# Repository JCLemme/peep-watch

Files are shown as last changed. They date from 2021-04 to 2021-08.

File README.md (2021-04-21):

# peep watch

I'm attempting to build some real nice rebbleos hardware. 

---

## the watches

Right now there's just the "big board" prototype. After that there'll be a smaller prototype that can actually be worn on the body and then, hopefully, an actually small watch. (assuming all the prototypes work as designed lol).

## contributing

Hit me up on the discord, documentation is still pretty light.

Datasheets go in ./common/datasheets, kicad libraries in ./common/kicad-libs. I've been using the nightly kicad 5.99 builds.

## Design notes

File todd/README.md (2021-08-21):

# "todd" prototype watch

Ok so this is the "big board" prototype. Everything broken out, huge pcb, erring on the side of excess, etc. Hopefully this design can just be taken and crammed onto a tiny lil board when we're ready to make some wearable prototypes.

[See the schematic here](./sch_export/todd_watch.pdf)

---

## theory of design

I'm trying to not stray too far from the designs of the original run of pebbles. I'm all in for messing with the "formula" in the future but right now we need more of the same, yeah? With that in mind the feature set hits the same notes:

* 32bit ARM cpu @ 128mhz with ~512k RAM
* 64mb flash storage
* JDI memory-in-pixel transflective LCD
* Four buttons
* IMU with magnetometer, gyroscope, etc.
* Microphone

It's a good starting place anyway. I'm not too worried about part commonality (practical reasons, the pebbles are getting up there in years) and once I abandoned that mindset things got wild. With that in mind -

## the changes

In no particular order

* The cpu was switched over from an STM32 to a shiny new Nordic part, the nRF5340. Along with the obvious improvements - more memory, more flash, more faster - it's a combo cpu + bluetooth part, so we don't need a separate bluetooth chip. It also has a dedicated networking core which might be useful for power reduction going forward.
* The display is a 176x176 model, up from 168x144. It's the closest display I could find to the originals.
* The IMU has a magnetometer built in - one fewer chip.
* The PMIC includes all the battery hardware, plus a haptic controller. Also about that -
* Swapped the ERM vibration motor for a linear resonant actuator. Welcome to the future bay bee
* NFC is also built into the cpu, so tap to pay might be a potential feature. Maybe. Hopefully.

## back to theory

I'd like this design to stay relevant and sourceable for a while so I'm choosing parts by what I can trust will be available long term. As of right now all the parts chosen are in stock at digikey, normally stocked by digikey, and have at least five years of availability on the roadmap. (Save for the display - it's in stock at arrow right now but it's a weird part with no good replacement so).

The board is gonna be big to support all the extra jumpers and breakouts and whatnot but it's gonna use the same packages (ideally) as the small version. These are gonna be nasty little BGAs and QFNs which means that most people won't be able to build one but them's the breaks. When everything is working I'm down to do a little manufacturing run with my oven, get some hardware to people.

---

## so does it work

Not yet

## when will it work

June, probably

## what's done

Schematic is looking good. Working on BOM and footprints now

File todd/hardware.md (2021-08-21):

# hardware description

All this is preliminary since I haven't built it yet lol.

---

## what it is

The big board is a huge prototype for the eventual smartwatch. It uses most (if not all) the same parts as the final watch, implements the same circuit the final watch will use (hopefully), and is a close enough hardware match to the final product that we can start porting rebbleos to it. In addition, it presents a bunch of test points and jumpers and whatnot so that we can prototype changes that will need to be made on the next prototype.

Jumpers are included on all the power rails to every chip. This is probably gonna go down as Lemme's Folly but it's my hope that it'll let me cut off broken sections of the board so that I don't have to build new ones every time I break something. They might also be useful for power optimization - just pop the jumper out and replace with an ammeter for accurate current measurements from any subcomponent.

## i don't get it

Working on some real documentation now. Until then I left little notes in the schematic.

---

## the goods

### Nordic Semiconductor nRF5340 - dual core Cortex M33 system-on-chip with Bluetooth LE and NFC

Full part number: NRF5340-QKAA-AB0-R7 ($9.90 at Digikey)

Package: aQFN94

Datasheet: [here](../common/datasheets/nRF5340_OPS_v0.5.1.pdf)

This part is still in development, but it seems far enough along to be useful. 

### Cypress Semiconductor S25FL512S - 512Mbit [Q]SPI Flash

Full part number: S25FL512SDSBHV210 ($9.12 at Digikey)

Package: 24-TBGA

Datasheet: [here](../common/datasheets/002-00488_S25FS512S_512_Mb_1.8_V_Serial_Peripheral_Interface_with_Multi-I_O_Non-Volatile_Flash.pdf)

### Bosch Sensortec BMX160 - 9 axis IMU with accelerometer, gyroscope, magnetometer

Full part number: BMX160 ($9.50 at Digikey)

Package: 14-VFLGA

Datasheet: [here](../common/datasheets/bst-bmx160-ds0001.pdf)

### Maxim Integrated MAX20353 - PWIM with battery charger, monitor, fuel gauge, haptic controller

Full part number: MAX20353AEWN+ ($9.37 at Digikey)

Package: 56-WFBGA

Datasheet: [here](../common/datasheets/MAX20353.pdf)

### Silicon Labs Si1151 - ambient light sensor

Full part number: SI1151-AB00-GM ($1.39 at Digikey)

Package: 10-WFQFN

Datasheet: [here](../common/datasheets/si115x-datasheet.pdf)

### Japan Display Inc. LPM013M126C - 176x176 transflective memory LCD with backlight

Full part number: LPM013M126C ($34.07 at Arrow)

Package: ribbon connector, 0.5mm pitch, 10 pins

Datasheet: [here](../common/datasheets/5lpm013m126c_specification_ver03.pdf)

### TDK InvenSense ICS-40619 - MEMS microphone

Full part number: ICS-40619 ($1.54 at Digikey)

Package: custom, 3.5x2.65x1.10mm 

Datasheet: [here](../common/datasheets/ICS-40619-Datasheet.pdf)

### Jinlong Machinery and Electronics, Inc. VLV041235L - linear resonant actuator

Full part number: VLV041235L ($3.61 at Digikey)

Package: custom, ribbon with two solder pads

Datasheet: [here](../common/datasheets/VLV041235L.pdf)

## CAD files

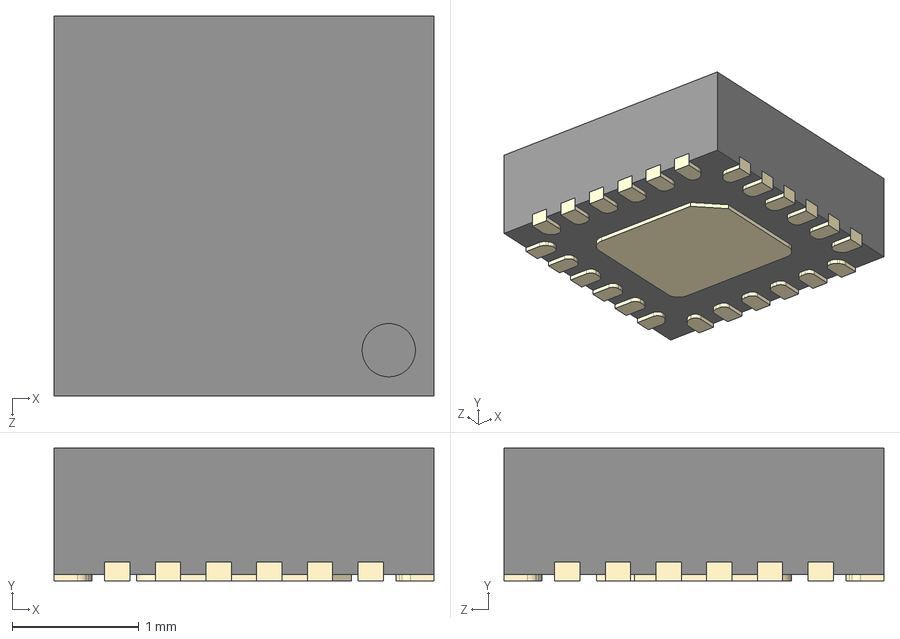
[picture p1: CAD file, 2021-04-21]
common/kicad-libs/ICM-20948.step
3.00 x 1.05 x 3.00 mm

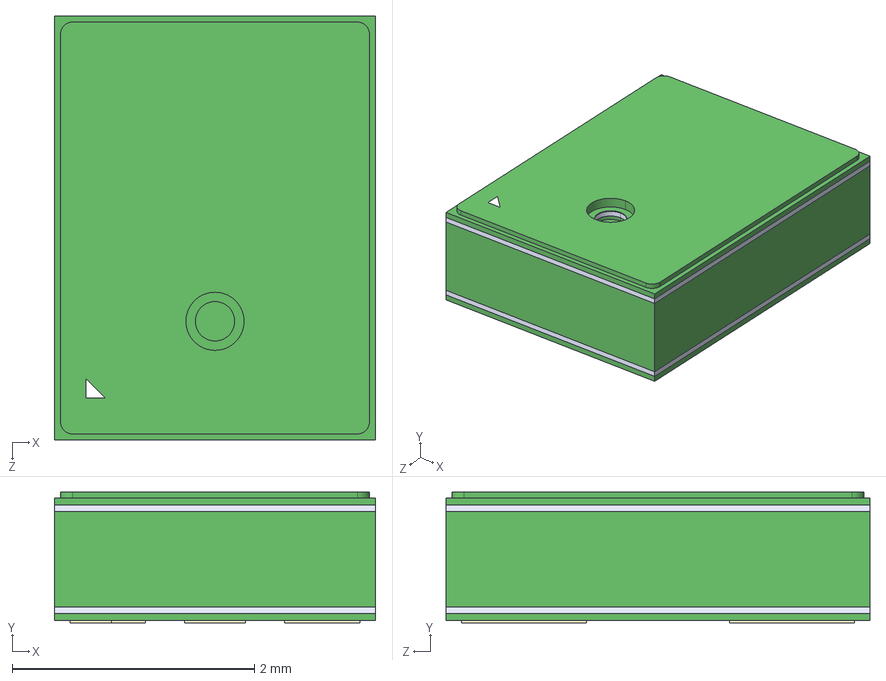
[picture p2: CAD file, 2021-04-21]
common/kicad-libs/ICS-40619.step
2.65 x 1.08 x 3.50 mm

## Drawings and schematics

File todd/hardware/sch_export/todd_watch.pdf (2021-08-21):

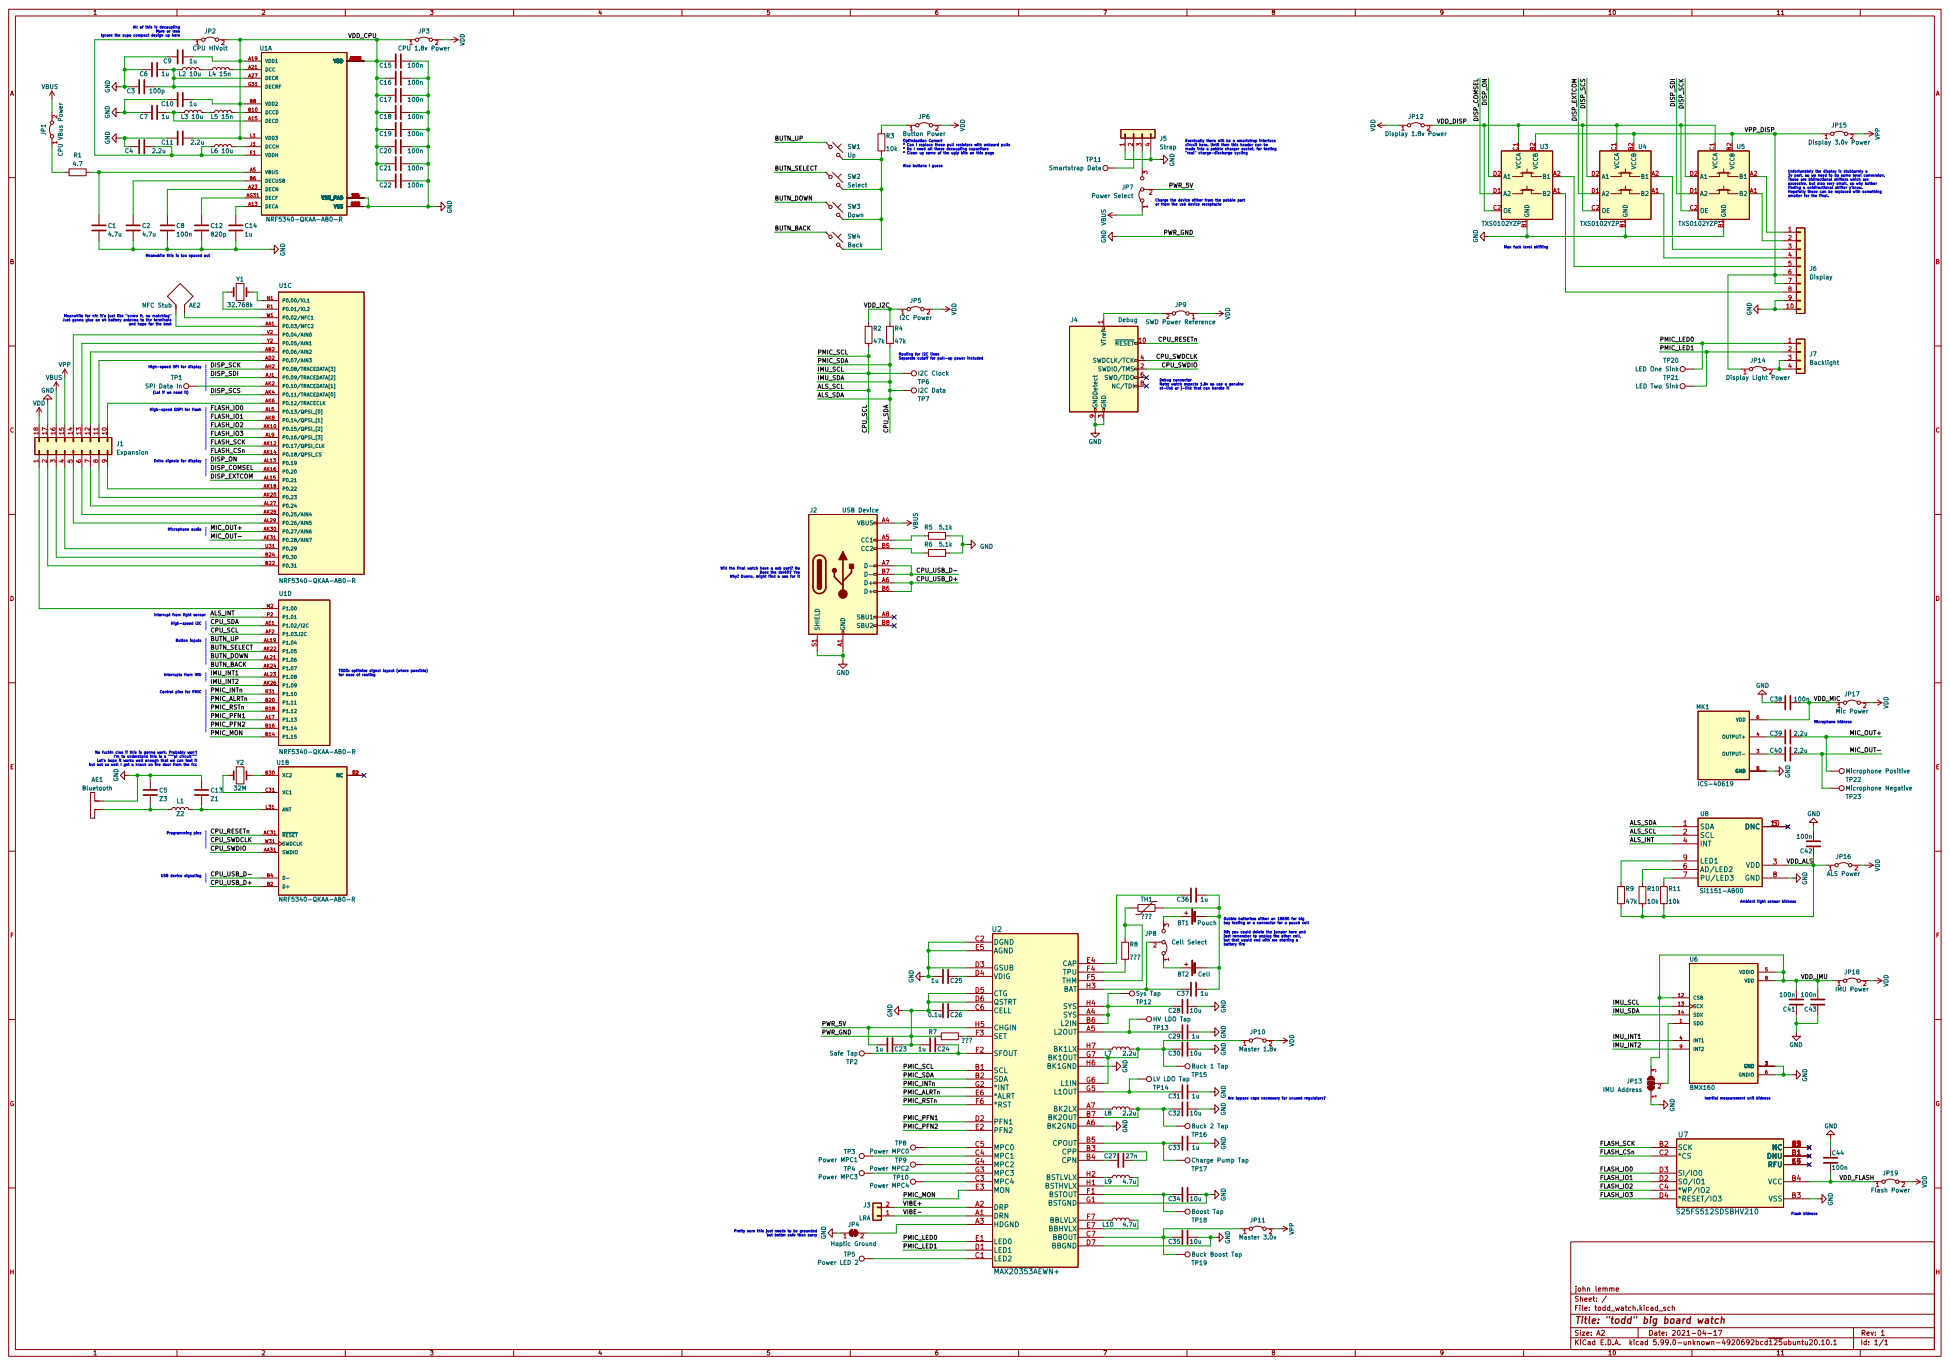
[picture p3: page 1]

All of this is decoupling More or less

Ignore the supa compact design up here

JP6 Button Power GND
* Clean up some of the ugly bits on this page Also buttons I guess Routing for I2C lines Separate cutoff for pull-up power included
JP11 Master 3.0v VDD VBUS

Eventually there will be a smartstrap interface
circuit here. Until then this header can be made into a pebble charger socket, for testing

* Do I need all these decoupling capacitors

"real" charge-discharge cycling

Unfortunately the display is stubbornly a
3v part, so we need to do some level conversion. These are bidirectional shifters which are excessive, but also very small, so why bother

finding a unidirectional shifter y'know. Hopefully these can be replaced with something

smaller for the final.

Man fuck level shifting

LED One Sink AE1 Bluetooth

High-speed SPI for display
TP1 SPI Data In

(Lol if we need it)

Extra signals for display

Will the final watch have a usb port? No Does the devkit? Yes Why? Dunno, might find a use for it Microphone audio No fuckin clue if this is gonna work. Probably won't

NRF5340-QKAA-AB0-R
Interrupt from light sensor Programming pins

TODO: optimize signal layout (where possible)

Control pins for PMIC

I'm to understand this is a """pi circuit""" Let's hope it works well enough that we can test it but not so well I get a knock on the door from the fcc

NB: you could delete the jumper here and

LV LDO Tap TP15 Buck 1 Tap

Are bypass caps necessary for unused regulators?

Inertial measurement unit bidness

Pretty sure this just needs to be grounded

but better safe than sorry

john lemme
File: todd_watch.kicad_sch Sheet: /
Id: 1/1 Title: "todd" big board watch

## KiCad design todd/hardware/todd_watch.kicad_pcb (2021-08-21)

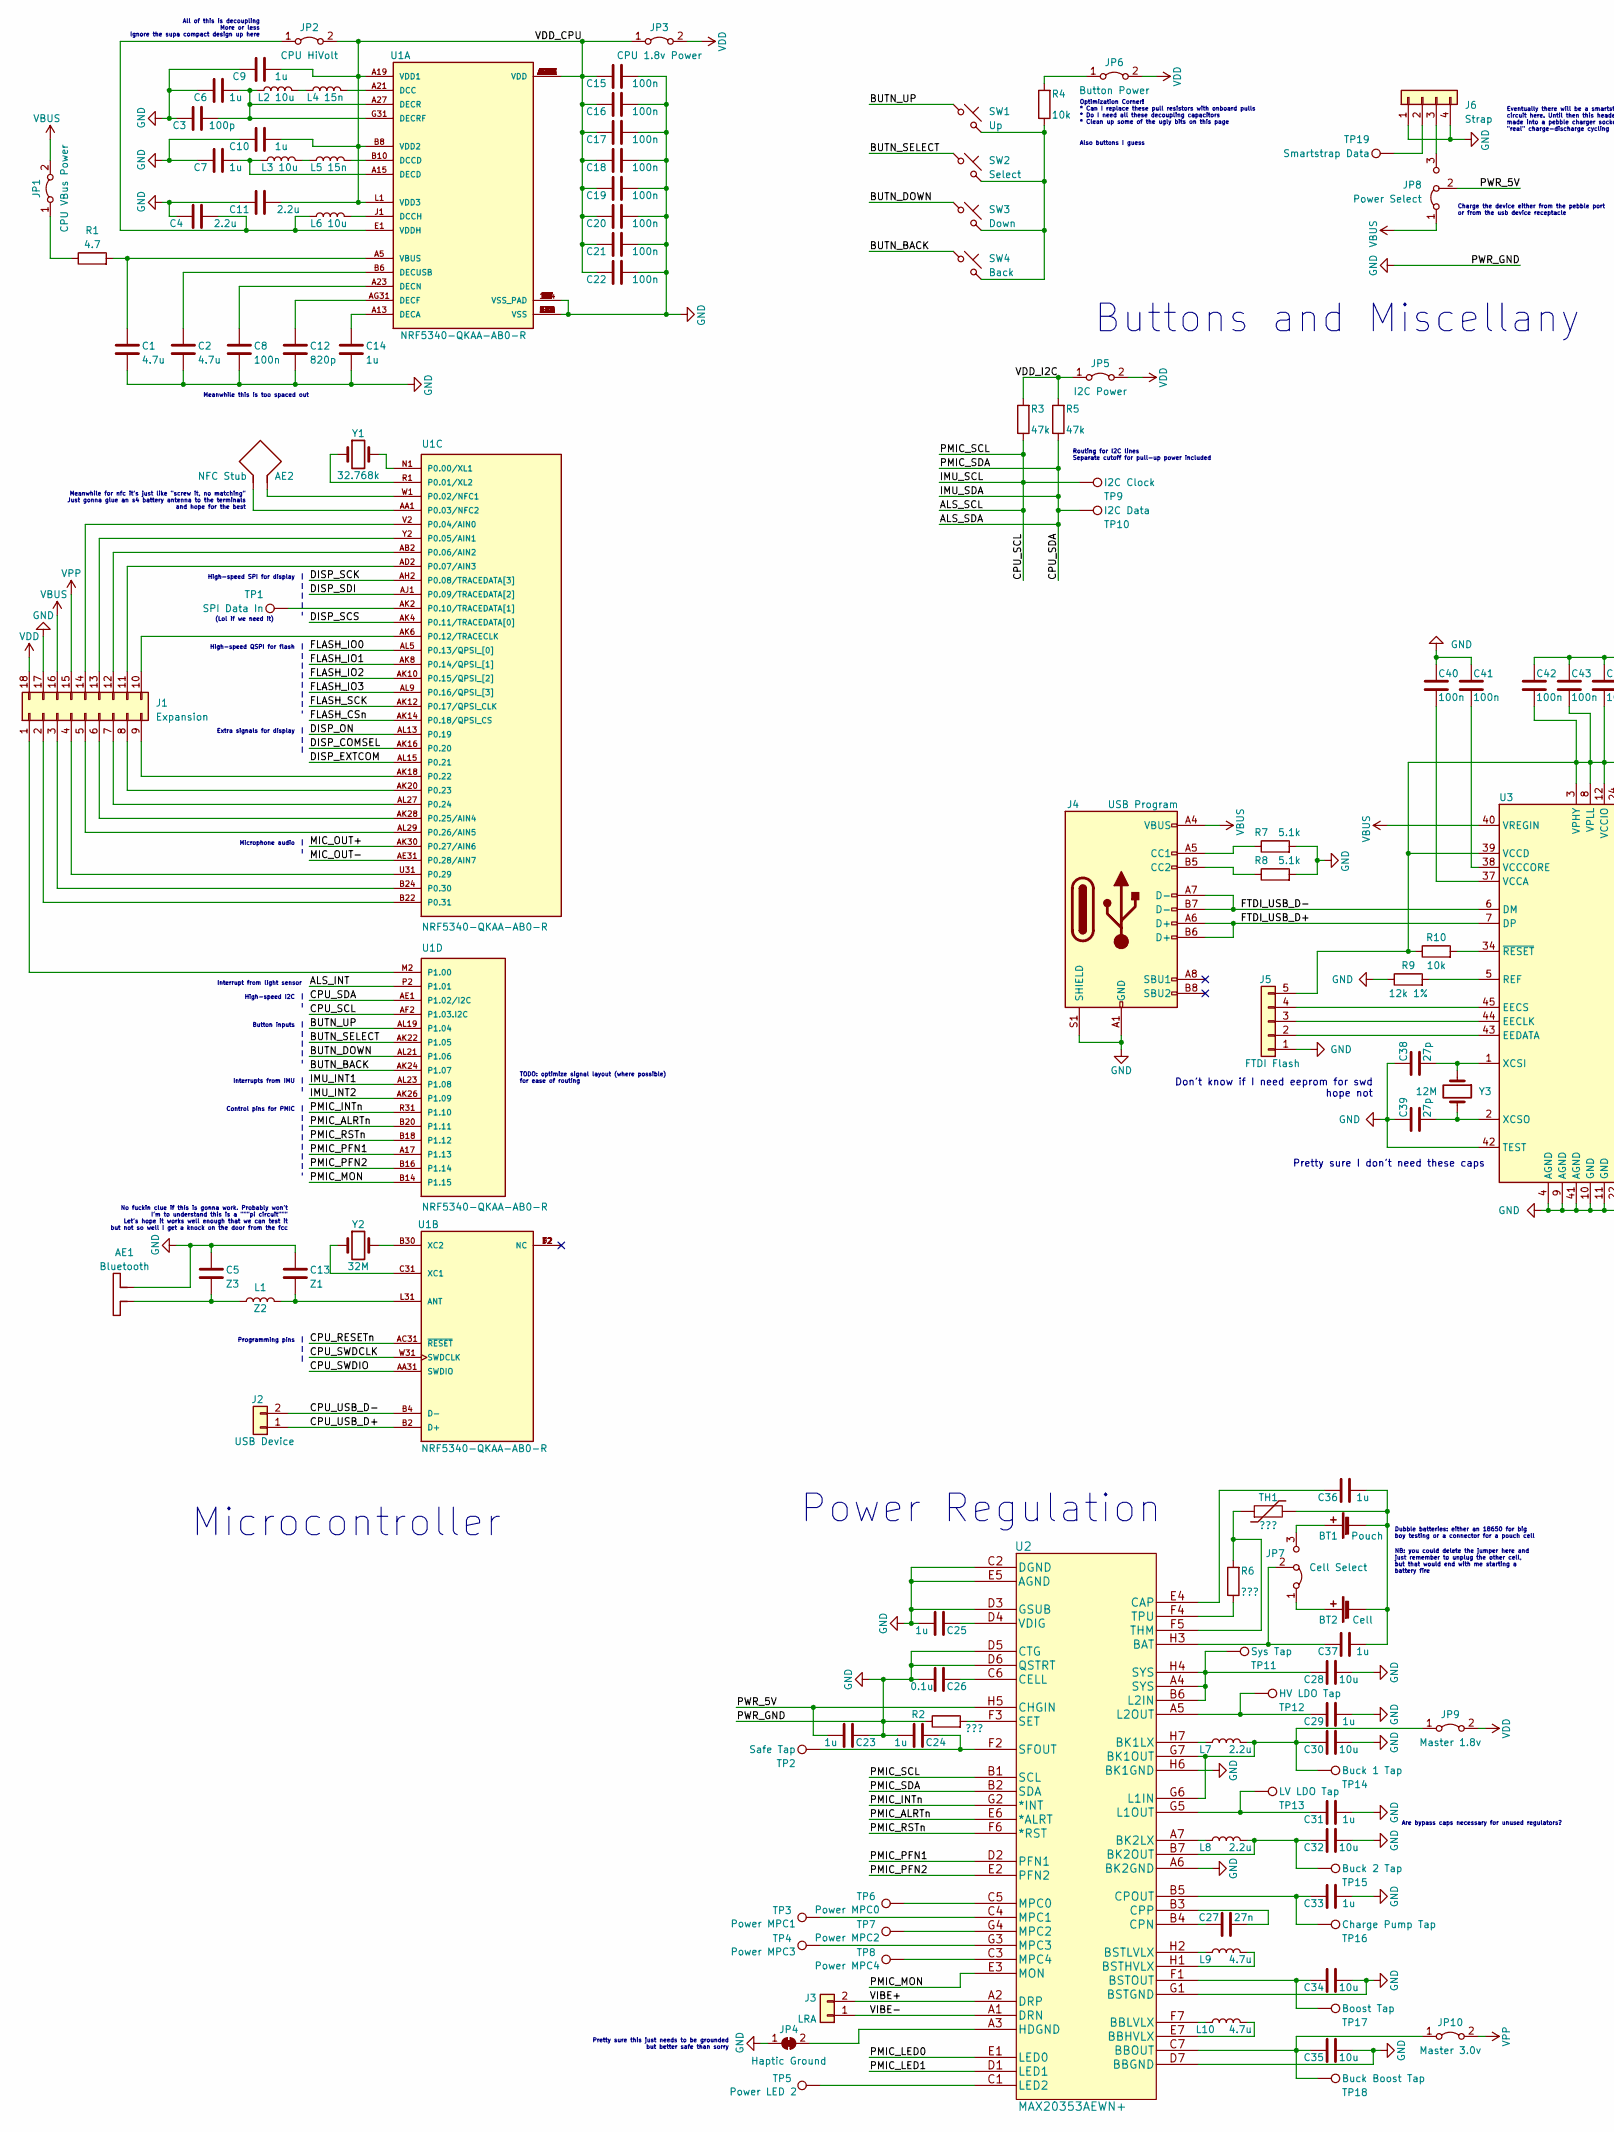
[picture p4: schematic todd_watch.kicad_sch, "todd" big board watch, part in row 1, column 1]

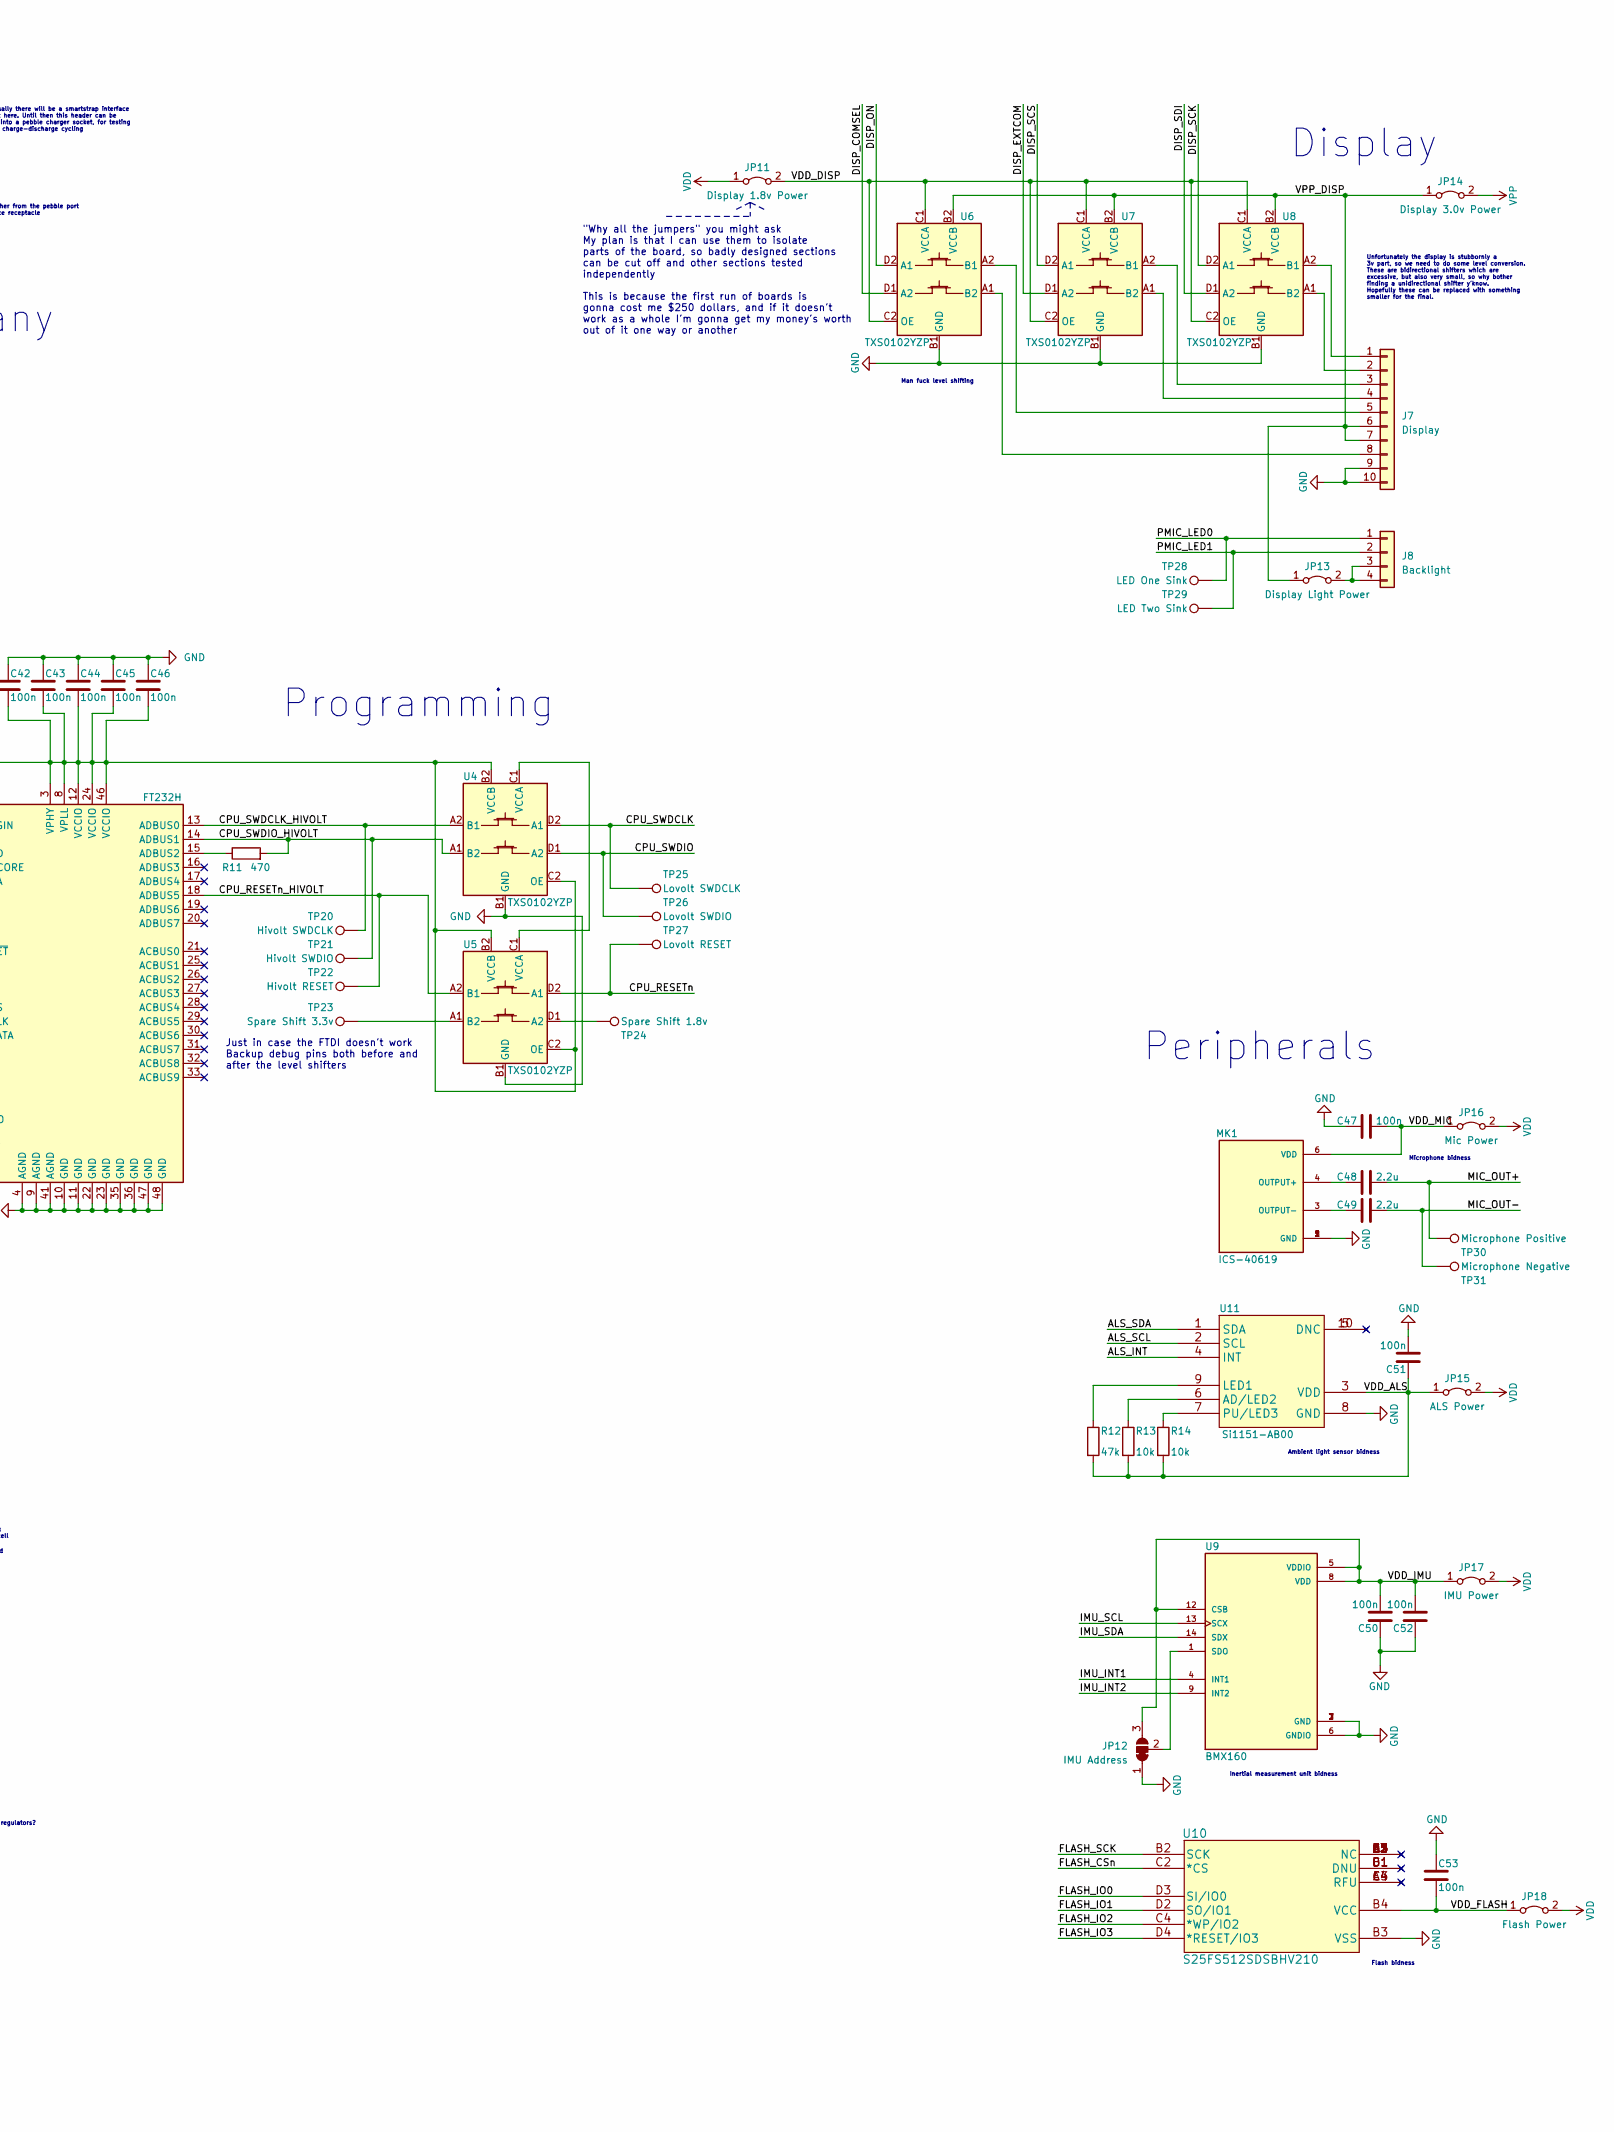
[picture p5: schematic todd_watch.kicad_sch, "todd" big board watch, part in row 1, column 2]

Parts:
AE1: Bluetooth; Texas_SWRA117D_2.4GHz_Left
AE2: NFC Stub; R_1206_3216Metric_Pad1.30x1.75mm_HandSolder
BT1: Pouch; PinSocket_1x02_P2.54mm_Vertical
BT2: Cell; BatteryHolder_Keystone_1042_1x18650
C1, C2: 4.7u; C_0603_1608Metric
C3: 100p; C_0603_1608Metric
C4, C11, C48, C49: 2.2u; C_0603_1608Metric
C5: Z3; C_0603_1608Metric
C6, C7, C9, C10, C14, C23, C24, C25, C29, C31, C33, C36, C37: 1u; C_0603_1608Metric
C8, C15, C16, C17, C18, C19, C20, C21, C22, C40, C41, C42, C43, C44, C45, C46, C47, C50, C51, C52, C53: 100n; C_0603_1608Metric
C12: 820p; C_0603_1608Metric
C13: Z1; C_0603_1608Metric
C26: 0.1u; C_0603_1608Metric
C27: 27n; C_0603_1608Metric
C28, C30, C32, C34, C35: 10u; C_0603_1608Metric
C38, C39: 27p; C_0603_1608Metric
J1: Expansion; PinSocket_2x09_P1.27mm_Vertical
J2: USB Device
J3: LRA; PinHeader_1x02_P2.54mm_Vertical
J4: USB Program; USB_C_Receptacle_XKB_U262-16XN-4BVC11
J5: FTDI Flash; PinHeader_1x05_P1.27mm_Vertical
J6: Strap; PinHeader_1x04_P2.54mm_Vertical
J7: Display; Hirose_FH12-10S-0.5SH_1x10-1MP_P0.50mm_Horizontal
J8: Backlight
JP1: CPU VBus Power; PinHeader_2x01_P1.27mm_Horizontal
JP2: CPU HiVolt; PinHeader_2x01_P1.27mm_Horizontal
JP3: CPU 1.8v Power; PinHeader_2x01_P1.27mm_Horizontal
JP4: Haptic Ground; SolderJumper-2_P1.3mm_Open_TrianglePad1.0x1.5mm
JP5: I2C Power; PinHeader_2x01_P1.27mm_Horizontal
JP6: Button Power; PinHeader_2x01_P1.27mm_Horizontal
JP7: Cell Select; PinHeader_1x03_P1.27mm_Horizontal
JP8: Power Select; PinHeader_1x03_P1.27mm_Horizontal
JP9: Master 1.8v; PinHeader_2x01_P1.27mm_Horizontal
JP10: Master 3.0v; PinHeader_1x02_P1.27mm_Horizontal
JP11: Display 1.8v Power; PinHeader_1x02_P1.27mm_Horizontal
JP12: IMU Address; SolderJumper-3_P2.0mm_Open_TrianglePad1.0x1.5mm_NumberLabels
JP13: Display Light Power; PinHeader_1x02_P1.27mm_Horizontal
JP14: Display 3.0v Power; PinHeader_1x02_P1.27mm_Horizontal
JP15: ALS Power; PinHeader_1x02_P1.27mm_Horizontal
JP16: Mic Power; PinHeader_1x02_P1.27mm_Horizontal
JP17: IMU Power; PinHeader_1x02_P1.27mm_Horizontal
JP18: Flash Power; PinHeader_1x02_P1.27mm_Horizontal
L1: Z2; L_0603_1608Metric
L2, L3, L6: 10u; L_0603_1608Metric
L4, L5: 15n; L_0603_1608Metric
L7, L8: 2.2u; L_0603_1608Metric
L9, L10: 4.7u; L_0603_1608Metric
MK1: ICS-40619; MIC_ICS-40619; PARTREV 1.0
R1: 4.7; R_0603_1608Metric
R2, R6: ???; R_0603_1608Metric
R3, R5, R12: 47k; R_0603_1608Metric
R4, R10, R13, R14: 10k; R_0603_1608Metric
R7, R8: 5.1k; R_0603_1608Metric
R9: 12k 1%; R_0603_1608Metric
R11: 470; R_0603_1608Metric
SW1: Up; SW_PUSH_6mm
SW2: Select; SW_PUSH_6mm
SW3: Down; SW_PUSH_6mm
SW4: Back; SW_PUSH_6mm
TH1: ???; C_0603_1608Metric
TP1: SPI Data In; TestPoint_Pad_D1.0mm
TP2: Safe Tap; TestPoint_Pad_D1.0mm
TP3: Power MPC1; TestPoint_Pad_D1.0mm
TP4: Power MPC3; TestPoint_Pad_D1.0mm
TP5: Power LED 2; TestPoint_Pad_D1.0mm
TP6: Power MPC0; TestPoint_Pad_D1.0mm
TP7: Power MPC2; TestPoint_Pad_D1.0mm
TP8: Power MPC4; TestPoint_Pad_D1.0mm
TP9: I2C Clock; TestPoint_Pad_D1.0mm
TP10: I2C Data; TestPoint_Pad_D1.0mm
TP11: Sys Tap; TestPoint_Pad_D1.0mm
TP12: HV LDO Tap; TestPoint_Pad_D1.0mm
TP13: LV LDO Tap; TestPoint_Pad_D1.0mm
TP14: Buck 1 Tap; TestPoint_Pad_D1.0mm
TP15: Buck 2 Tap; TestPoint_Pad_D1.0mm
TP16: Charge Pump Tap; TestPoint_Pad_D1.0mm
TP17: Boost Tap; TestPoint_Pad_D1.0mm
TP18: Buck Boost Tap; TestPoint_Pad_D1.0mm
TP19: Smartstrap Data; TestPoint_Pad_D1.0mm
TP20: Hivolt SWDCLK; TestPoint_Pad_D1.0mm
TP21: Hivolt SWDIO; TestPoint_Pad_D1.0mm
TP22: Hivolt RESET; TestPoint_Pad_D1.0mm
TP23: Spare Shift 3.3v; TestPoint_Pad_D1.0mm
TP24: Spare Shift 1.8v; TestPoint_Pad_D1.0mm
TP25: Lovolt SWDCLK; TestPoint_Pad_D1.0mm
TP26: Lovolt SWDIO; TestPoint_Pad_D1.0mm
TP27: Lovolt RESET; TestPoint_Pad_D1.0mm
TP28: LED One Sink; TestPoint_Pad_D1.0mm
TP29: LED Two Sink; TestPoint_Pad_D1.0mm
TP30: Microphone Positive; TestPoint_Pad_D1.0mm
TP31: Microphone Negative; TestPoint_Pad_D1.0mm
U1: NRF5340-QKAA-AB0-R; XCVR_NRF5340-QKAA-AB0-R; PARTREV 1.0
U2: MAX20353AEWN+; MAX20353AEWN&plus_
U3: FT232H; LQFP-48_7x7mm_P0.5mm
U4, U5, U6, U7, U8: TXS0102YZP; Texas_DSBGA-8_0.9x1.9mm_Layout2x4_P0.5mm
U9: BMX160; PQFN50P250X300X100-14N; PARTREV 1.2
U10: S25FS512SDSBHV210; S25FL512SAGBHIC10
U11: Si1151-AB00; 10-WFQFN
Y1: 32.768k; Crystal_SMD_2012-2Pin_2.0x1.2mm
Y2: 32M; Crystal_SMD_2012-2Pin_2.0x1.2mm
Y3: 12M; Crystal_SMD_2012-2Pin_2.0x1.2mm

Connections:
/ALS_INT: U1.P2 (P1.01), U11.4 (INT)
/ALS_SCL: R3.1, TP9.1, U1.AF2 (P1.03.I2C), U2.B1 (SCL), U9.13 (SCX), U11.2 (SCL)
/ALS_SDA: R5.1, TP10.1, U1.AE1 (P1.02/I2C), U2.B2 (SDA), U9.14 (SDX), U11.1 (SDA)
/BUTN_BACK: SW4.1, U1.AK24 (P1.07)
/BUTN_DOWN: SW3.1, U1.AL21 (P1.06)
/BUTN_SELECT: SW2.1, U1.AK22 (P1.05)
/BUTN_UP: SW1.1, U1.AL19 (P1.04)
/CPU_RESETn: TP27.1, U1.AC31 (~RESET), U5.D2 (A1)
/CPU_RESETn_HIVOLT: TP22.1, U3.18 (ADBUS5), U5.A2 (B1)
/CPU_SWDCLK: TP25.1, U1.W31 (SWDCLK), U4.D2 (A1)
/CPU_SWDCLK_HIVOLT: TP20.1, U3.13 (ADBUS0), U4.A2 (B1)
/CPU_SWDIO: TP26.1, U1.AA31 (SWDIO), U4.D1 (A2)
/CPU_SWDIO_HIVOLT: R11.2, TP21.1, U3.14 (ADBUS1), U4.A1 (B2)
/CPU_USB_D+: J2.1, U1.B2 (D+)
/CPU_USB_D-: J2.2, U1.B4 (D-)
/DISP_COMSEL: U1.AK16 (P0.20), U6.D1 (A2)
/DISP_EXTCOM: U1.AL15 (P0.21), U7.D1 (A2)
/DISP_ON: U1.AL13 (P0.19), U6.D2 (A1)
/DISP_SCK: U1.AH2 (P0.08/TRACEDATA[3]), U8.D2 (A1)
/DISP_SCS: U1.AK4 (P0.11/TRACEDATA[0]), U7.D2 (A1)
/DISP_SDI: U1.AJ1 (P0.09/TRACEDATA[2]), U8.D1 (A2)
/FLASH_CSn: U1.AK14 (P0.18/QPSI_CS), U10.C2 (*CS)
/FLASH_IO0: U1.AL5 (P0.13/QPSI_[0]), U10.D3 (SI/IO0)
/FLASH_IO1: U1.AK8 (P0.14/QPSI_[1]), U10.D2 (SO/IO1)
/FLASH_IO2: U1.AK10 (P0.15/QPSI_[2]), U10.C4 (*WP/IO2)
/FLASH_IO3: U1.AL9 (P0.16/QPSI_[3]), U10.D4 (*RESET/IO3)
/FLASH_SCK: U1.AK12 (P0.17/QPSI_CLK), U10.B2 (SCK)
/FTDI_USB_D+: J4.A6 (D+), J4.B6 (D+), U3.7 (DP)
/FTDI_USB_D-: J4.A7 (D-), J4.B7 (D-), U3.6 (DM)
/IMU_INT1: U1.AL23 (P1.08), U9.4 (INT1)
/IMU_INT2: U1.AK26 (P1.09), U9.9 (INT2)
/MIC_OUT+: C48.1, TP30.1, U1.AK30 (P0.27/AIN6)
/MIC_OUT-: C49.1, TP31.1, U1.AE31 (P0.28/AIN7)
/PMIC_ALRTn: U1.B20 (P1.11), U2.E6 (*ALRT)
/PMIC_INTn: U1.R31 (P1.10), U2.G2 (*INT)
/PMIC_LED0: J8.1, TP28.1, U2.E1 (LED0)
/PMIC_LED1: J8.2, TP29.1, U2.D1 (LED1)
/PMIC_MON: U1.B14 (P1.15), U2.E3 (MON)
/PMIC_PFN1: U1.A17 (P1.13), U2.D2 (PFN1)
/PMIC_PFN2: U1.B16 (P1.14), U2.E2 (PFN2)
/PMIC_RSTn: U1.B18 (P1.12), U2.F6 (*RST)
/PWR_5V: C23.2, JP8.2 (C), U2.H5 (CHGIN)
/VDD_ALS: C51.1, JP15.1 (A), R12.2, R13.2, R14.2, U11.3 (VDD)
/VDD_CPU: C9.2, C10.2, C11.2, C15.1, C16.1, C17.1, C18.1, C19.1, C20.1, C21.1, C22.1, JP2.2 (B), JP3.1 (A), U1.A19 (VDD1), U1.AC1 (VDD), U1.AG1 (VDD), U1.AJ31 (VDD), U1.AL3 (VDD), U1.AL7 (VDD), U1.AL11 (VDD), U1.AL17 (VDD), U1.AL25 (VDD), U1.B8 (VDD2), U1.B28 (VDD), U1.C1 (VDD), U1.E31 (VDD), U1.L1 (VDD3), U1.N31 (VDD), U1.U1 (VDD)
/VDD_DISP: JP11.2 (B), U6.C1 (VCCA), U6.C2 (OE), U7.C1 (VCCA), U7.C2 (OE), U8.C1 (VCCA), U8.C2 (OE)
/VDD_FLASH: C53.2, JP18.1 (A), U10.B4 (VCC)
/VDD_I2C: JP5.1 (A), R3.2, R5.2
/VDD_IMU: C50.2, C52.2, JP12.3 (B), JP17.1 (A), U9.5 (VDDIO), U9.8 (VDD), U9.12 (CSB)
/VDD_MIC: C47.1, JP16.1 (A), MK1.6 (VDD)
/VIBE+: J3.2, U2.A2 (DRP)
/VIBE-: J3.1, U2.A1 (DRN)
/VPP_DISP: J7.6, J7.7, JP13.1 (A), JP14.1 (A), U6.B2 (VCCB), U7.B2 (VCCB), U8.B2 (VCCB)
GND: AE1.2, C1.2, C2.2, C3.1, C4.1, C5.2, C6.1, C7.1, C8.2, C9.1, C10.1, C11.1, C12.2, C13.2, C14.2, C15.2, C16.2, C17.2, C18.2, C19.2, C20.2, C21.2, C22.2, C23.1, C24.2, C25.2, C26.2, C28.2, C29.2, C30.2, C31.2, C32.2, C33.2, C34.2, C35.2, C38.1, C39.1, C40.1, C41.1, C42.1, C43.1, C44.1, C45.1, C46.1, C47.2, C50.1, C51.2, C52.1, C53.1, J1.17, J4.A1 (GND), J4.A12 (GND), J4.B1 (GND), J4.B12 (GND), J4.S1 (SHIELD), J5.1, J6.1, J6.4, J7.9, J7.10, JP4.1 (A), JP12.1 (A), MK1.1 (GND), MK1.2 (GND), MK1.5 (GND), R2.1, R7.2, R8.2, R9.1, U1.35 (VSS_PAD), U1.36 (VSS_PAD), U1.37 (VSS_PAD), U1.38 (VSS_PAD), U1.39 (VSS_PAD), U1.40 (VSS_PAD), U1.41 (VSS_PAD), U1.43 (VSS_PAD), U1.44 (VSS_PAD), U1.45 (VSS_PAD), U1.46 (VSS_PAD), U1.47 (VSS_PAD), U1.48 (VSS_PAD), U1.49 (VSS_PAD), U1.50 (VSS_PAD), U1.51 (VSS_PAD), U1.104 (VSS_PAD), U1.A25 (VSS), U1.B12 (VSS), U1.B26 (VSS), U1.G1 (VSS), U1.H2 (VSS), U1.J31 (VSS), U2.A6 (BK2GND), U2.C2 (DGND), U2.D3 (GSUB), U2.D5 (CTG), U2.D6 (QSTRT), U2.D7 (BBGND), U2.E5 (AGND), U2.G1 (BSTGND), U2.H6 (BK1GND), U3.4 (AGND), U3.9 (AGND), U3.10 (GND), U3.11 (GND), U3.22 (GND), U3.23 (GND), U3.35 (GND), U3.36 (GND), U3.41 (AGND), U3.42 (TEST), U3.47 (GND), U3.48 (GND), U4.B1 (GND), U5.B1 (GND), U6.B1 (GND), U7.B1 (GND), U8.B1 (GND), U9.2 (GND), U9.3 (GND), U9.6 (GNDIO), U9.7 (GND), U10.B3 (VSS), U11.8 (GND)
unnamed: AE1.1, C5.1, L1.1
unnamed: AE2.1, U1.AA1 (P0.03/NFC2)
unnamed: AE2.2, U1.W1 (P0.02/NFC1)
unnamed: BT1.1 (+), JP7.3 (B)
unnamed: BT1.2 (-), BT2.2 (-), C36.2, C37.2, TH1.2
unnamed: BT2.1 (+), JP7.1 (A)
unnamed: C1.1, R1.2, U1.A5 (VBUS)
unnamed: C2.1, U1.B6 (DECUSB)
unnamed: C3.2, C6.2, L2.1, U1.A27 (DECR), U1.G31 (DECRF)
unnamed: C4.2, JP2.1 (A), L6.1, U1.E1 (VDDH)
unnamed: C7.2, L3.1, U1.A15 (DECD)
unnamed: C8.1, U1.A23 (DECN)
unnamed: C12.1, U1.AG31 (DECF)
unnamed: C13.1, L1.2, U1.L31 (ANT)
unnamed: C14.1, U1.A13 (DECA)
unnamed: C24.1, TP2.1, U2.F2 (SFOUT)
unnamed: C25.1, U2.D4 (VDIG)
unnamed: C26.1, U2.C6 (CELL)
unnamed: C27.1, U2.B4 (CPN)
unnamed: C27.2, U2.B3 (CPP)
unnamed: C28.1, TP11.1, U2.A4 (SYS), U2.B6 (L2IN), U2.H4 (SYS)
unnamed: C29.1, TP12.1, U2.A5 (L2OUT)
unnamed: C30.1, JP9.1 (A), L7.2, TP14.1, U2.G6 (L1IN), U2.G7 (BK1OUT)
unnamed: C31.1, TP13.1, U2.G5 (L1OUT)
unnamed: C32.1, L8.2, TP15.1, U2.B7 (BK2OUT)
unnamed: C33.1, TP16.1, U2.B5 (CPOUT)
unnamed: C34.1, TP17.1, U2.F1 (BSTOUT)
unnamed: C35.1, JP10.1 (A), TP18.1, U2.C7 (BBOUT)
unnamed: C36.1, U2.E4 (CAP)
unnamed: C37.1, JP7.2 (C), U2.H3 (BAT)
unnamed: C38.2, U3.1 (XCSI), Y3.1
unnamed: C39.2, U3.2 (XCSO), Y3.2
unnamed: C40.2, U3.37 (VCCA)
unnamed: C41.2, U3.38 (VCCCORE)
unnamed: C42.2, C43.2, C44.2, C45.2, C46.2, J5.5, R10.1, U3.3 (VPHY), U3.8 (VPLL), U3.12 (VCCIO), U3.24 (VCCIO), U3.39 (VCCD), U3.46 (VCCIO), U4.B2 (VCCB), U4.C2 (OE), U5.B2 (VCCB), U5.C2 (OE)
unnamed: C48.2, MK1.4 (OUTPUT+)
unnamed: C49.2, MK1.3 (OUTPUT-)
unnamed: J1.1, U1.M2 (P1.00)
unnamed: J1.2, U1.B22 (P0.31)
unnamed: J1.3, U1.B24 (P0.30)
unnamed: J1.4, U1.U31 (P0.29)
unnamed: J1.5, U1.AL29 (P0.26/AIN5)
unnamed: J1.6, U1.AK28 (P0.25/AIN4)
unnamed: J1.7, U1.AL27 (P0.24)
unnamed: J1.8, U1.AK20 (P0.23)
unnamed: J1.9, U1.AK18 (P0.22)
unnamed: J1.10, U1.AK6 (P0.12/TRACECLK)
unnamed: J1.11, U1.AD2 (P0.07/AIN3)
unnamed: J1.12, U1.AB2 (P0.06/AIN2)
unnamed: J1.13, U1.Y2 (P0.05/AIN1)
unnamed: J1.14, U1.V2 (P0.04/AIN0)
unnamed: J4.A5 (CC1), R7.1
unnamed: J4.B5 (CC2), R8.1
unnamed: J5.2, U3.43 (EEDATA)
unnamed: J5.3, U3.44 (EECLK)
unnamed: J5.4, U3.45 (EECS)
unnamed: J6.2, TP19.1
unnamed: J6.3, JP8.3 (B)
unnamed: J7.1, U8.A2 (B1)
unnamed: J7.2, U8.A1 (B2)
unnamed: J7.3, U7.A2 (B1)
unnamed: J7.4, U7.A1 (B2)
unnamed: J7.5, U6.A2 (B1)
unnamed: J7.8, U6.A1 (B2)
unnamed: J8.3, J8.4, JP13.2 (B)
unnamed: JP1.1 (A), R1.1
unnamed: JP4.2 (B), U2.A3 (HDGND)
unnamed: JP6.1 (A), R4.2
unnamed: JP12.2 (C), U9.1 (SDO)
unnamed: L2.2, L4.1
unnamed: L3.2, L5.1
unnamed: L4.2, U1.A21 (DCC)
unnamed: L5.2, U1.B10 (DCCD)
unnamed: L6.2, U1.J1 (DCCH)
unnamed: L7.1, U2.H7 (BK1LX)
unnamed: L8.1, U2.A7 (BK2LX)
unnamed: L9.1, U2.H2 (BSTLVLX)
unnamed: L9.2, U2.H1 (BSTHVLX)
unnamed: L10.1, U2.F7 (BBLVLX)
unnamed: L10.2, U2.E7 (BBHVLX)
unnamed: R2.2, U2.F3 (SET)
unnamed: R4.1, SW1.2, SW2.2, SW3.2, SW4.2
unnamed: R6.1, U2.F4 (TPU)
unnamed: R6.2, TH1.1, U2.F5 (THM)
unnamed: R9.2, U3.5 (REF)
unnamed: R10.2, U3.34 (~RESET)
unnamed: R11.1, U3.15 (ADBUS2)
unnamed: R12.1, U11.9 (LED1)
unnamed: R13.1, U11.6 (AD/LED2)
unnamed: R14.1, U11.7 (PU/LED3)
unnamed: TP1.1, U1.AK2 (P0.10/TRACEDATA[1])
unnamed: TP3.1, U2.C4 (MPC1)
unnamed: TP4.1, U2.G3 (MPC3)
unnamed: TP5.1, U2.C1 (LED2)
unnamed: TP6.1, U2.C5 (MPC0)
unnamed: TP7.1, U2.G4 (MPC2)
unnamed: TP8.1, U2.C3 (MPC4)
unnamed: TP23.1, U5.A1 (B2)
unnamed: TP24.1, U5.D1 (A2)
unnamed: U1.B30 (XC2), Y2.2
unnamed: U1.C31 (XC1), Y2.1
unnamed: U1.N1 (P0.00/XL1), Y1.2
unnamed: U1.R1 (P0.01/XL2), Y1.1
unnamed: U4.C1 (VCCA), U5.C1 (VCCA)
VBUS: J1.16, J4.A4 (VBUS), J4.A9 (VBUS), J4.B4 (VBUS), J4.B9 (VBUS), JP1.2 (B), JP8.1 (A), U3.40 (VREGIN)
VDD: J1.18, JP3.2 (B), JP5.2 (B), JP6.2 (B), JP9.2 (B), JP11.1 (A), JP15.2 (B), JP16.2 (B), JP17.2 (B), JP18.2 (B)
VPP: J1.15, JP10.2 (B), JP14.2 (B)

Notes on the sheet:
Microcontroller
Meanwhile for nfc it's just like "screw it, no matching" Just gonna glue an s4 battery antenna to the terminals and hope for the best
All of this is decoupling More or less Ignore the supa compact design up here
(Lol if we need it)
No fuckin clue if this is gonna work. Probably won't I'm to understand this is a """pi circuit""" Let's hope it works well enough that we can test it but not so well I get a knock on the door from the fcc
High-speed SPI for display
High-speed QSPI for flash
Extra signals for display
Microphone audio
High-speed I2C
Button inputs
Interrupts from IMU
Control pins for PMIC
Programming pins
Interrupt from light sensor
Meanwhile this is too spaced out
TODO: optimize signal layout (where possible) for ease of routing
Pretty sure this just needs to be grounded but better safe than sorry
Power Regulation
Routing for I2C lines Separate cutoff for pull-up power included
Optimization Corner! * Can I replace these pull resistors with onboard pulls * Do I need all these decoupling capacitors * Clean up some of the ugly bits on this page
Also buttons I guess
Buttons and Miscellany
Don't know if I need eeprom for swd hope not
Dubble batteries: either an 18650 for big boy testing or a connector for a pouch cell
NB: you could delete the jumper here and just remember to unplug the other cell, but that would end with me starting a battery fire
Are bypass caps necessary for unused regulators?
Charge the device either from the pebble port or from the usb device receptacle
Pretty sure I don't need these caps
Eventually there will be a smartstrap interface circuit here. Until then this header can be made into a pebble charger socket, for testing "real" charge-discharge cycling
Just in case the FTDI doesn't work Backup debug pins both before and after the level shifters
Programming
"Why all the jumpers" you might ask My plan is that I can use them to isolate parts of the board, so badly designed sections can be cut off and other sections tested independently
This is because the first run of boards is gonna cost me $250 dollars, and if it doesn't work as a whole I'm gonna get my money's worth out of it one way or another
Man fuck level shifting
Peripherals
Display
Inertial measurement unit bidness
Unfortunately the display is stubbornly a 3v part, so we need to do some level conversion. These are bidirectional shifters which are excessive, but also very small, so why bother finding a unidirectional shifter y'know. Hopefully these can be replaced with something smaller for the final.
Ambient light sensor bidness

Board: 2 copper layers, 156 parts (0 on the bottom side), 157 nets, no tracks yet.

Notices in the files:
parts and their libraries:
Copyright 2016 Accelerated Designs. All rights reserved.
